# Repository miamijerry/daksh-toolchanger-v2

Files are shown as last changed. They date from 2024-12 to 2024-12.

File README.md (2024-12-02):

# FORK OF DAKSH V2 3D Printed Tool Changer - Open Beta
* This fork has files I used to build my Daksh Tool Changer.
* Frame is a Trident Easybake 350 cubed.
* I am using my own remix of Funday's V2ool Toolbody's.
* Pictures of my mods are in the Readme.md's of each MiamiJerry individual Usermod Folder.
#
DAKSH V2 3D Printed Tool Changer is a fully 3D printed mechanical tool changer compatible with different CoreXY platforms like the Voron Trident, 1.8, 2.4  and RatRig VCore 3. The servo less mechanical locking mechanism is inspired by the Prusa XL - but is fully 3d printed with metal inserts in the critical areas for rigidity and reliability.

Salient Features: 

  * Fully Mechanical Tool Changer
  * Ultra Fast tool changing time of under 4 seconds
  * Fully 3d Printed and assembled using off the shelf components - no machined parts required
  * Intelligent Error State Detection and Recovery minimizing failed prints
  * Intelligent Tool Heating Management for faster and efficient prints
  * Automatic XYZ calibration across the different tools
  * Capable of High accelerations and print speeds
  * Minimal loss in build space with the tool changer addition
  * Integrated nozzle ooze blockers for clean prints with minimal waste
  * Status LEDs on each toolhead for accurate visual state diagnosis
  * Custom Klipper configuration, modules and macros for an integrated software package
  * Stiff Wire Looms and recoil management - wire looms are entirely contained within the printer frame itself.
  * Fully Enclosed Design in the same design ethos as the original Voron Trident design - giving it the ability to print high temp materials like ABS, PA6-CF and PC-CF etc which require enclosed chambers.

The design is open source and can be used freely for non commercial purposes. 

Do join the discord group at the link below and subscribe to the Youtube channel for more updates and interesting projects like this.

* [Github](https://github.com/ankurv2k6/wp-daksh-toolchanger-v2)
* [Youtube](https://www.youtube.com/channel/UCr8K1tva2CaEhyqNyaEjq_w)
* [Daksh V2 Discord](https://discord.gg/HQWDepWG)
* [BOM](https://github.com/ankurv2k6/daksh-toolchanger-v2/tree/main/BOM) Create a copy of this [Google sheet](https://docs.google.com/spreadsheets/d/11UvXF6FBCVRHxjejWgnOjJhMhHBDZpzY7ktGSjUUAWM/edit?usp=sharing) for a checklist

Build Log and Demo videos 
* COMING SOON....

**5 Colour PLA Print - 0.6mm Nozzle / 0.25 Layer Height / 23 Hours / 2000 Tool Changes - TimeLapse**
Vase Print (https://www.youtube.com/watch?v=5WeLoIn3UTw)
  
**5 Colour PLA Print - 0.6mm Nozzle / 0.25 Layer Height / 23 Hours / 2000 Tool Changes**


**5 Colour PLA Print - 0.6mm Nozzle / 0.25 Layer Height / 3 Hours / 300 Tool Changes**  


**TPU + PLA Print - 0.6mm Nozzle / 0.25 Layer Height / 23 Hours / 2000 Tool Changes**  


**TPU + PLA Print - 0.6mm Nozzle / 0.25 Layer Height / 8 Hours / 900 Tool Changes**  


**5 Colour PLA + PETG Support print - 0.6mm Nozzle / 0.25 Layer Height / 3 Hours / 600 Tool Changes**  


Build Images
* COMING SOON....

Attributions - This project uses elements from a bunch of different projects by awesome people out there - I will be including a list of credits soon. My apologies for not doing that at the very onset due to paucity of time.

* [Quad Belted Z in based on the excellent work by genevamotion & thiagolocatelli](https://github.com/3DPrintingMods/VoronTrident-BeltedZ)

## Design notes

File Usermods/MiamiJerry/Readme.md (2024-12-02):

This MiamiJerry Usermods folder contains my modified STL's which I used to build my Daksh Tool Changer. See
https://discord.com/channels/1226812716514021460/1262827455429873727/threads/1269819858682642522

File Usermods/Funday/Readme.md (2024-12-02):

Repository of Funday's files from 
https://discord.com/channels/1226812716514021460/1262827455429873727/threads/1262827796820918292

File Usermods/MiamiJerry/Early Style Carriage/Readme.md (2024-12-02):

Made a number of changes to the original Carriage ( Uses pins to secure the belts)
* Carriage warps when printed, added cut-away supports to maintain dimensions after the carriage cools.
* Interference between carriage and Toolbody connectors (aka MGN12's), added 1.5mm deep pockets to carriage.
* Carriage in Fusion measures 102.7mm tall and V2ool toolbody center section measures 104mm, Scaled carriage to 101% for printed dimension of 103.9
* Toolbody connectors (aka MGN12's) are too long and tool does not fully compress springs, Printed toolbody connectors with a 23mm and 23.5 centers with 693zz bearings.
* Pins that limit the sliders, are replaced by M3x40 screws, so the sliders can be replaced without removing or disassembling the Carriage.
* Jack screw holes added to Carriage, so the springs can be fully depress when adjusting / tightning the toolbody connectors to the V2ool body.
* Carriage_w_CutAway_Supports
23mm Toolbody Connector 693ZZ

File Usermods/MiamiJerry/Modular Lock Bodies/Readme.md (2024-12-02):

These are my files to add Modular Pin Blocks to the lock bodies.
Note. Drive the pins in from opposite sides, so the distance between the pins are parallel.
#
Lower_Lock_Body
Upper_Lock_Body

Pin_Block
Pin_Block_005
Pin_Block_010

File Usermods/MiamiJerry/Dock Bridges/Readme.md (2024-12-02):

These are my files to add a bridge across the backside of the docks. 
* Purpose is to make the docks very rigid.
* Provides cable magement for the USB cables, Power Wires and PTFE tubes.
#
Dimensions on a Trident 350 frame;
* 74.4mm spacing between docks for 5 V2ools Toolbodies.
* 86.6mm between mating faces of docks.
* 12.2mm thickness of the docks.
#



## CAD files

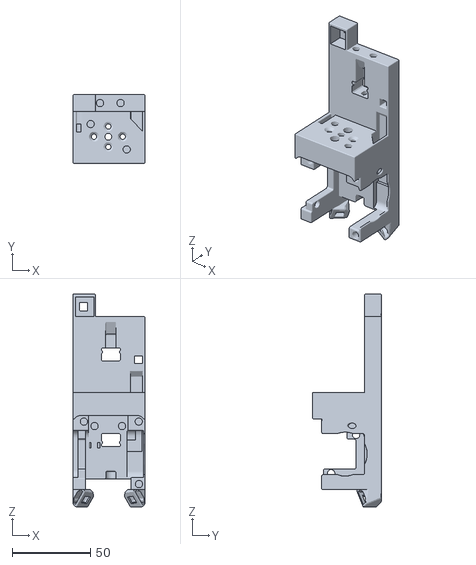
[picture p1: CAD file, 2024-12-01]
Usermods/Funday/TD6S_Sherpa_Mini_Toolhead_Funday.stl
46.0 x 43.8 x 136.0

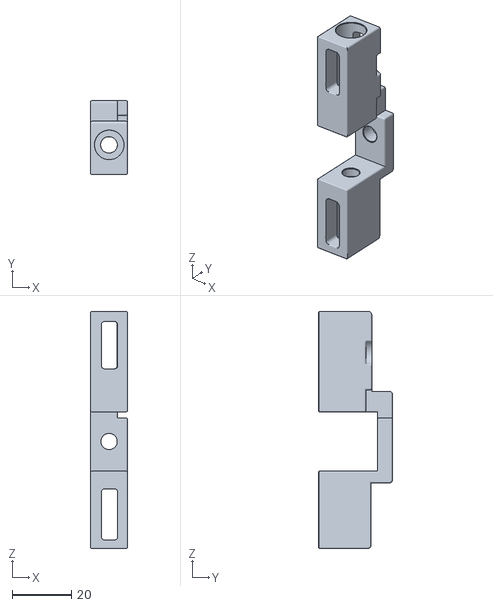
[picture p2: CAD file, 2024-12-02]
Usermods/MiamiJerry/Dock Bridges/Trimmed_20mm_Deep_2020_Dock_Mount.stl
12.5 x 25.0 x 80.2

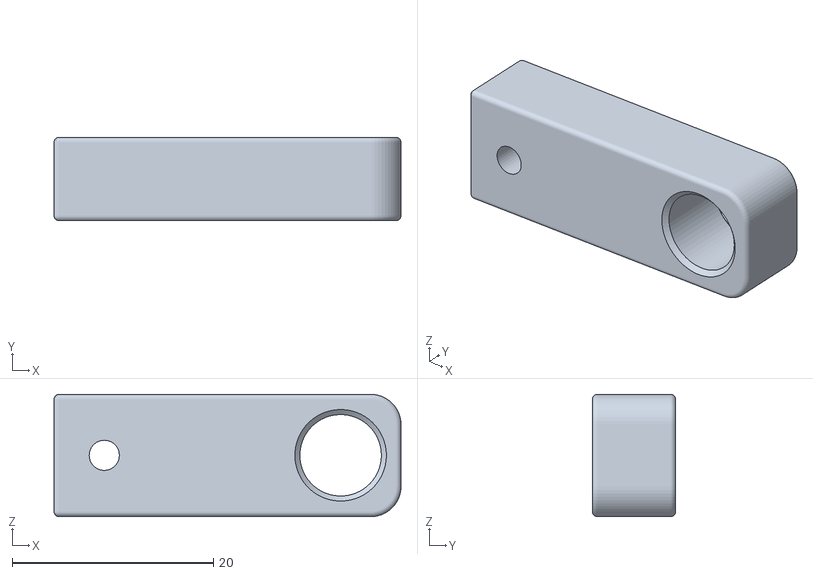
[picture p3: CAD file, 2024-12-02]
Usermods/MiamiJerry/Early Style Carriage/ToolBody_Connector_23.5_693ZZ .stl
34.5 x 8.30 x 12.2

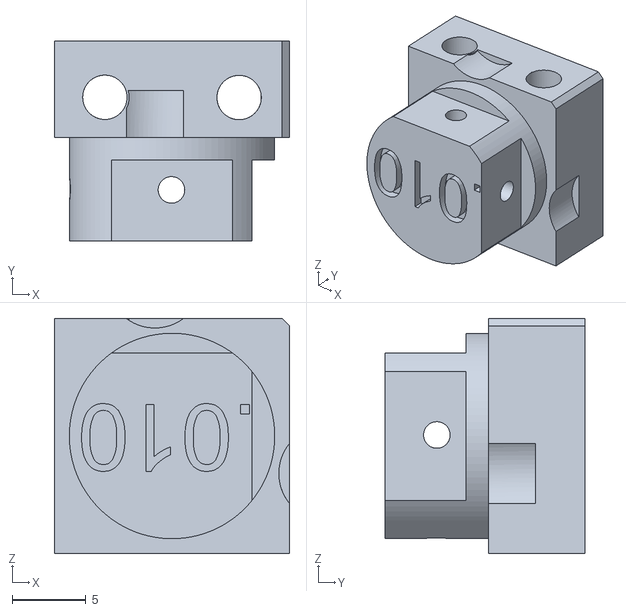
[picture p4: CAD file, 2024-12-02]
Usermods/MiamiJerry/Modular Lock Bodies/BEST_FIT_Plus_.010_Universal_Lock_Block.stl
15.9 x 13.5 x 15.9

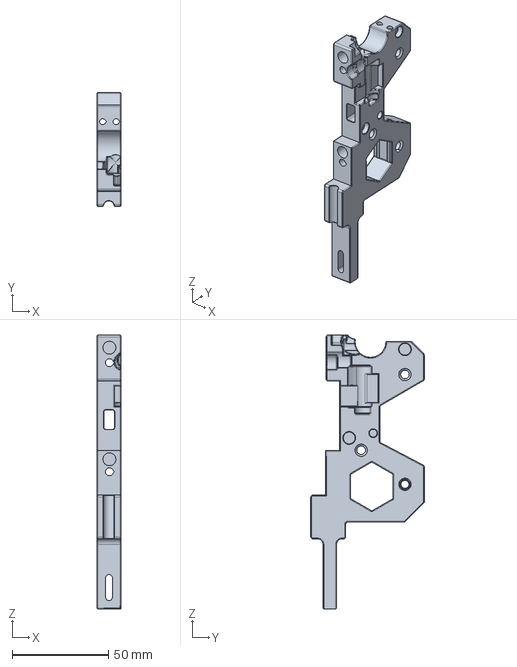
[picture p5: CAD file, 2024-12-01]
Usermods/Funday/Daksh_V2ool_Dock_RD_v3_v1.step
12.5 x 59.0 x 142.3 mm

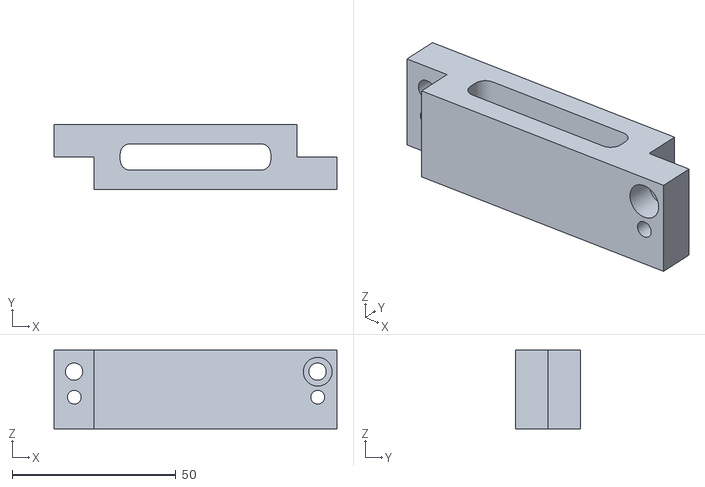
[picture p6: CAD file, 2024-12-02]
Usermods/MiamiJerry/Dock Bridges/R1_Top_2-4.stl
86.5 x 20.0 x 24.0

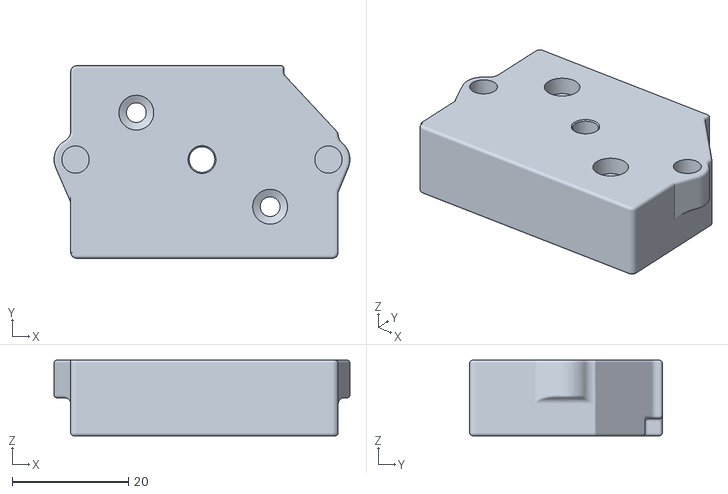
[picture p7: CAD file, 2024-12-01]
Usermods/Funday/Sherpa_Mini_Extruder_Plate_Funday.stl
50.9 x 33.1 x 13.0

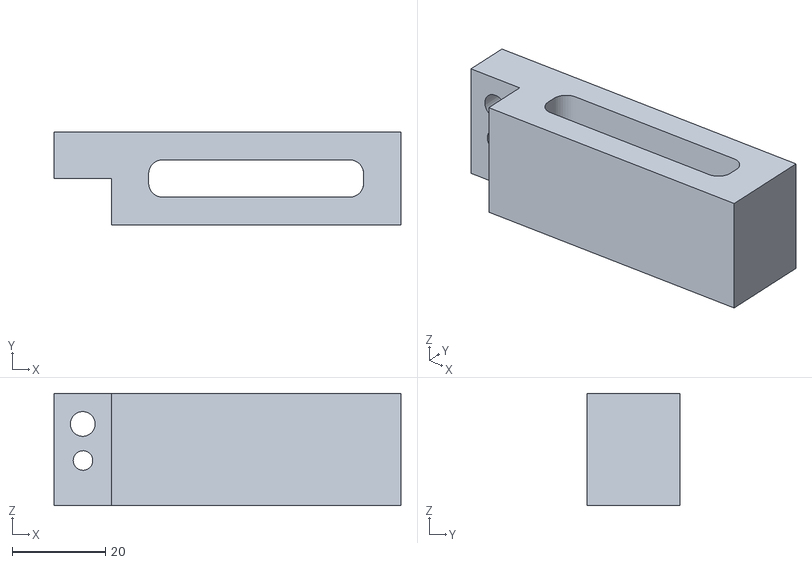
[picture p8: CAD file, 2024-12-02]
Usermods/MiamiJerry/Dock Bridges/R1_Top_5.stl
74.2 x 20.0 x 24.0

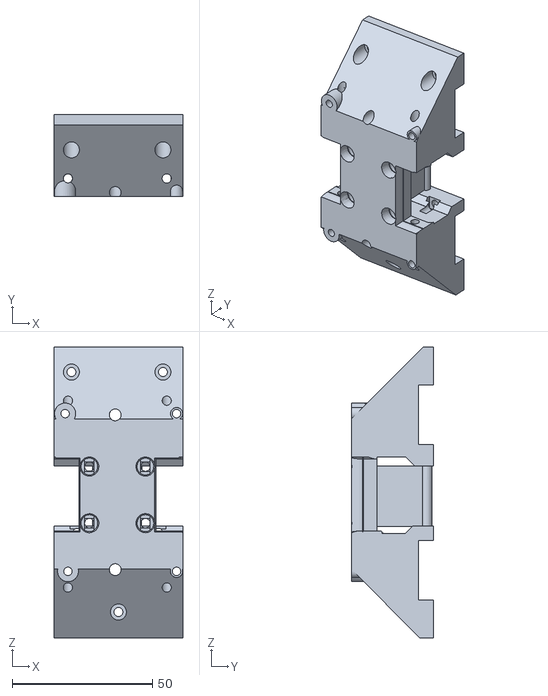
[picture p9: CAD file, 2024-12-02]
Usermods/MiamiJerry/Early Style Carriage/Scaled_101_R5-Tool_Lock_Carriage.stl
45.9 x 29.3 x 103.8

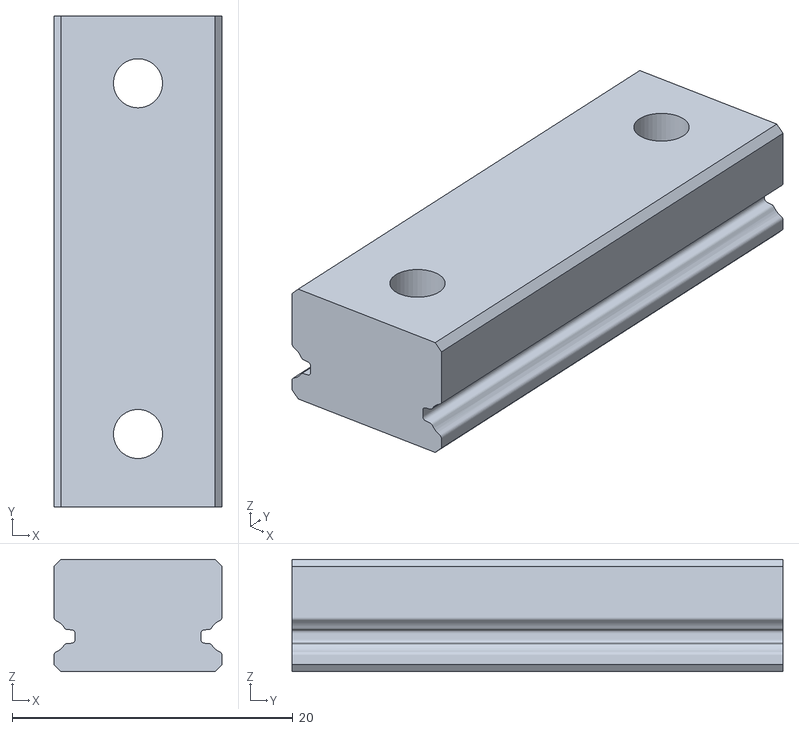
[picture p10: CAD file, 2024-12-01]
Usermods/Funday/MGN12_Rail_Sectionl.stl
12.0 x 35.0 x 8.00

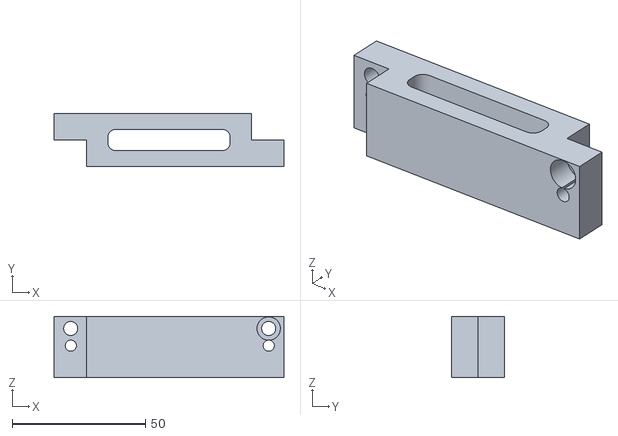
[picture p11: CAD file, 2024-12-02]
Usermods/MiamiJerry/Dock Bridges/R1_Bottom_2-4.stl
86.4 x 20.0 x 23.0

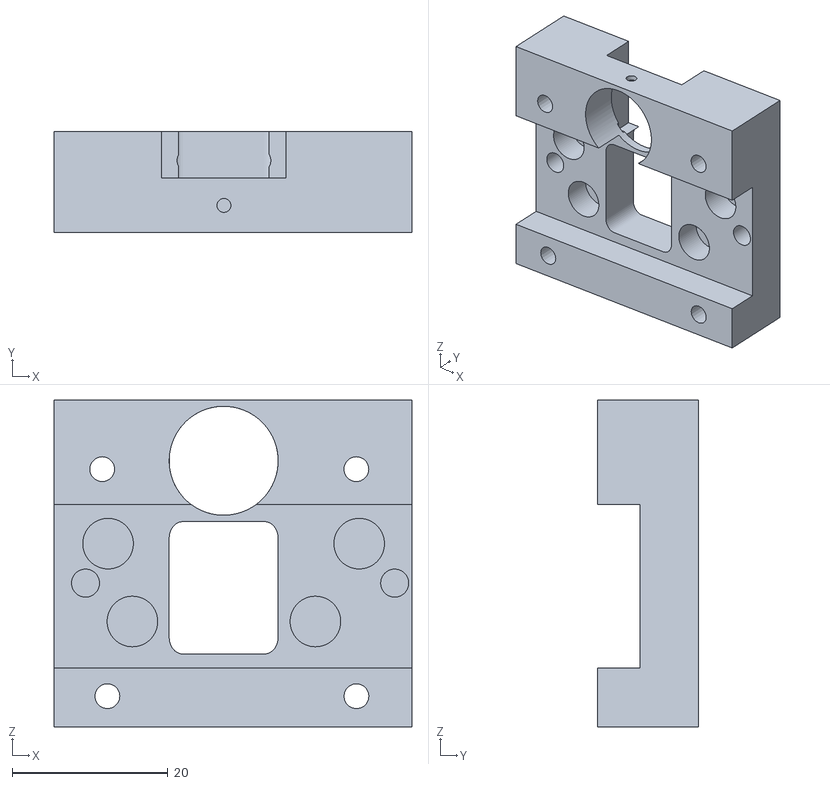
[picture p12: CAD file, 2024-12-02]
Usermods/MiamiJerry/Modular Lock Bodies/V2_Modular_Original_lock-body-top.stl
46.0 x 13.0 x 42.0

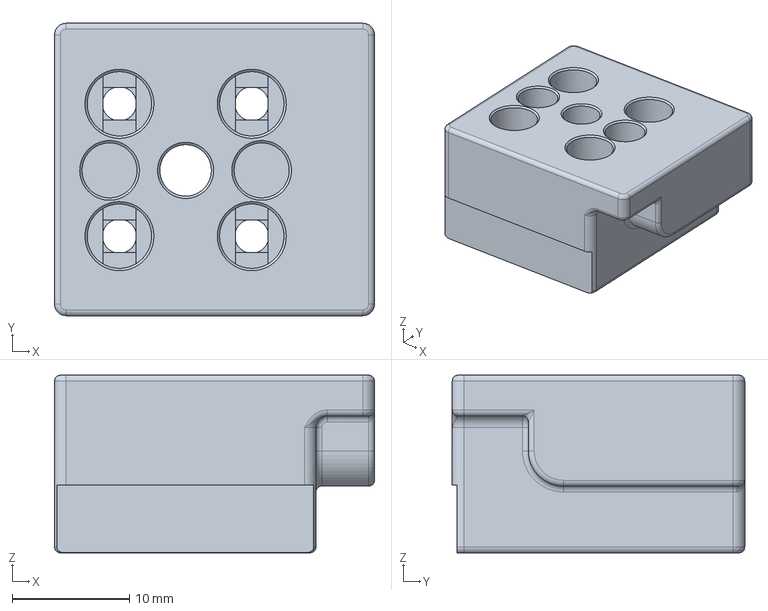
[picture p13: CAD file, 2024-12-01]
Usermods/Funday/Daksh_V2ool_RD_Beta_v3_Dragon_Mount_v1.step
27.3 x 25.0 x 15.2 mm

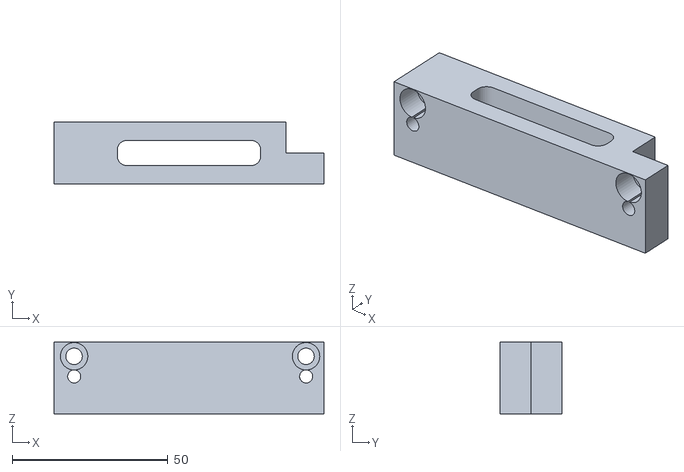
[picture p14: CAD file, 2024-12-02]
Usermods/MiamiJerry/Dock Bridges/R1_Bottom_1.stl
86.6 x 20.0 x 23.0

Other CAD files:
Usermods/MiamiJerry/Early Style Carriage/ToolBody_Connector_23.0_693ZZ .stl
Usermods/MiamiJerry/Modular Lock Bodies/OnSize_5.97-5.99-OpposingPins_Universal_Lock_Block.stl
Usermods/MiamiJerry/Modular Lock Bodies/Plus_.005_Universal_Lock_Block.stl
Usermods/MiamiJerry/Modular Lock Bodies/V3_Modular_Original_lock-body-bottom.stl
Usermods/Funday/BTT Fan Body Orion w sensor mount.stl
Usermods/Funday/BTT_Omron_Fan_Body.step
Usermods/Funday/BTT_Omron_Fan_Body_v1.step
Usermods/Funday/Daksh_V2ool_RD_Beta_v3_Sherpa_Mini_Extruder_Plate_v1.step
Usermods/Funday/Dock_5_31_24.stl
Usermods/Funday/EBB36_Cover.stl
Usermods/Funday/EBB36_Mount_Sherpa_Mini.stl
Usermods/Funday/Ebb36_Mount_Sherpa_Mini.step
Usermods/Funday/Ebb_36_Cover.step
Usermods/Funday/Fan_Grille.stl
Usermods/Funday/Power_Umbilical_Sleeve.stl
Usermods/Funday/Scaled_101_percent_BTT Fan Body Orion w sensor mount.stl
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
